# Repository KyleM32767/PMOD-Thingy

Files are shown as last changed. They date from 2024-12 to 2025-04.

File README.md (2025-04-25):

# PMOD-Thingy

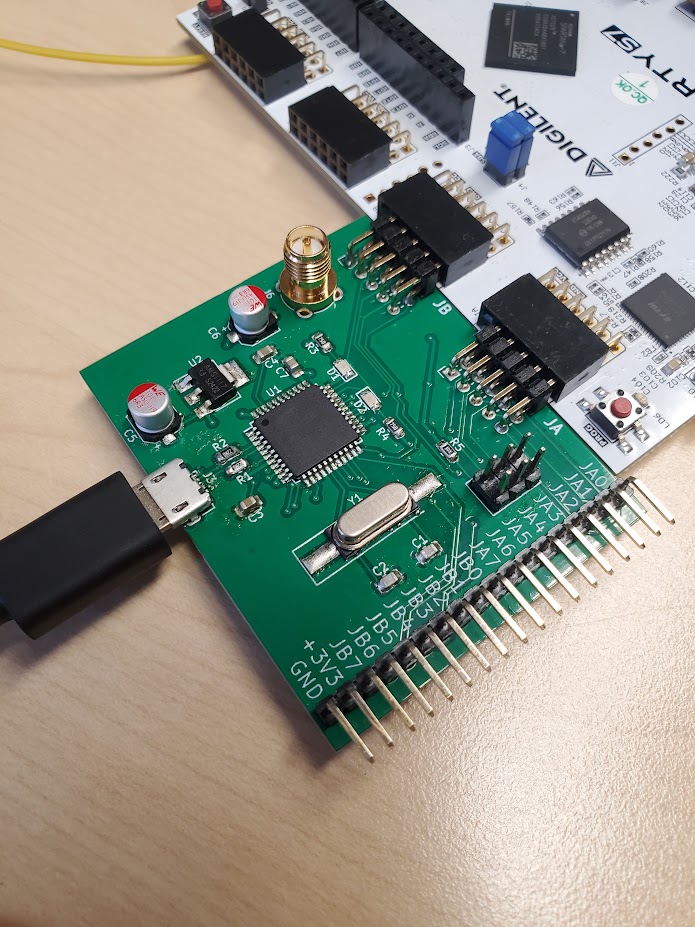
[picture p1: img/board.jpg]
PMOD thingy plugged into Arty S7


PMOD Thingy is, essentially, an Arduino Leonardo modified and repackaged to interface with basically any Digilent FPGA board via the PMOD headers. I designed it to streamline hardware security experiments done by myself and my colleagues at WPI Vernam Lab, where we'd use a 3.3V Arduino board to interface with an FPGA through the PMOD headers.

**Note: this is a custom board with a different pinout and clock frequency from a typical Arduino, so you must follow the setup procedure before use!**

## Pinouts

```
                  (top edge of board)
_______________________________________________________
-----------------------         -----------------------
| GND JB3 JB2 JB1 JB0 |         | GND JA3 JA2 JA1 JA0 |
| GND JB7 JB6 JB5 JB4 |         | GND JA7 JA6 JA5 JA4 |
-----------------------         -----------------------
```

| PMOD header | Digital I/O pin | Atmega32U4 pin |
|:---|:---|:---|
| JA0 | 0 | PB0 |
| JA1 | 1 / SPI SCK | PB1 |
| JA2 | 2 / SPI MOSI | PB2 |
| JA3 | 3 / SPI MISO | PB3 |
| JA4 | 4 | PB4 |
| JA5 | 5 | PB5 |
| JA6 | 6 | PB6 |
| JA7 | 7 | PB7 |
| JB0 | 8 / I2C SCL | PD0 |
| JB1 | 9 / I2C SDA | PD1 |
| JB2 | 10 / UART RX | PD2 |
| JB3 | 11 / UART TX | PD3 |
| JB4 | 12 | PD4 |
| JB5 | 13 | PD5 |
| JB6 | 14 | PD6 |
| JB7 | 15 | PD7 |

Although you can use the digital I/O numbers, there are macros for the PMOD headers, so you don't have to keep track of which header connects to which pin.

```cpp
// output 0 on JA6
pinMode(JA6, OUTPUT);
digitalWrite(JA6, LOW);

// input on JB2
pinMode(JB2, INPUT);
if (digitalRead(JB2) == HIGH)
	Serial.println("1 on JB2");
else
	Serial.println("0 on JB2");
```

Each PMOD header is also connected to a single port on the Atmega32U4, which means you can also read and write them bytewise using the data direction and port registers if that is more your speed. There are the macros `DDR_JA`/`DDR_JB` (data direction), `PIN_JA`/`PIN_JB` (input), and `PORT_JA`/`PORT_JB` (output) for that purpose. For more information, refer to [section 10.4 of the ATmega32U4 datasheet](https://ww1.microchip.com/downloads/en/devicedoc/atmel-7766-8-bit-avr-atmega16u4-32u4_datasheet.pdf#page=84). This makes reading and writing multiple bits much, much faster. The code snippet below is functionally identical to the one above...

```cpp
// output 0 on JA6
DDR_JA |= (1<<6);
PORT_JA &= ~(1<<6);

// read input on JB2
DDR_JB %= ~(1<<2);
if (PIN_JB & (1<<2))
	Serial.println("1 on JB2");
```

## Burning the bootloader

You can burn the bootloader to the PMOD thingy as you would any other Arduino board through the Arduino IDE. I prefer to do this with [another Arduino running ArduinoISP](https://docs.arduino.cc/built-in-examples/arduino-isp/ArduinoISP/) personally. It doesn't actually matter if you use a 3.3V or a 5V board, so long as you do not connect the PMOD Thingy to any other power source (i.e. USB) while using it. Just remember the capacitor between reset and ground!

**PLEASE NOTE: I MADE A MISTAKE!** If you have one of the original v1 boards I made, I mixed up the SPI pins, so a few of the ICSP pins (SCK, MOSI, MISO) are wrong, though VCC, GND, and RESET are correct. I corrected the labels for the SPI pins on the schematic in this repository and this readme, but not on the layout and gerber files, so if you make one of these yourself you will have this issue as well. In order to burn the bootloader from an Arduino Uno as ISP, you need to make the following connections...

| Pin | Arduino Uno as ISP | PMOD Thingy V1 |
|:---|:---|:---|
| MOSI  | D11 / ICSP-4 | JA2 |
| MISO  | D12 / ICSP-1 | JA3 |
| SCK | D13 / ICSP-3 | JA1 |
| reset | D10 | ICSP-5 |

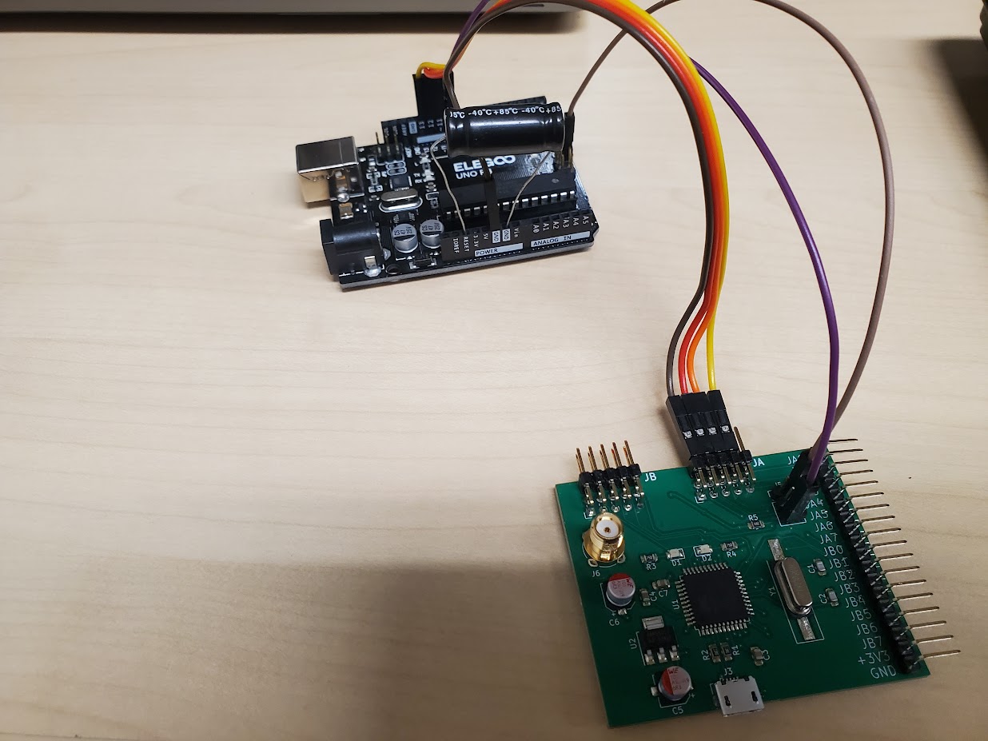
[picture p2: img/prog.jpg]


The PMOD Thingy runs the same bootloader as the Sparkfun Pro Micro 3.3V / 8MHz, though you can use the bootloader for any Atmega32u4-based Arduino with an 8MHz clock (as opposed to the 16MHz clock most boards run), if any other such boards exist at all. As such, you will need to [install the pro micro board to the Arduino IDE](https://learn.sparkfun.com/tutorials/pro-micro--fio-v3-hookup-guide#windows_boardaddon). Once that is installed, set up and connect your ArduinoISP, select "SparkFun Pro Micro" under *Tools>Board*, select "ATmega32U4 (3.3V, 8MHz)" under *Tools>Processor*, then click *Tools>Burn Bootloader*.

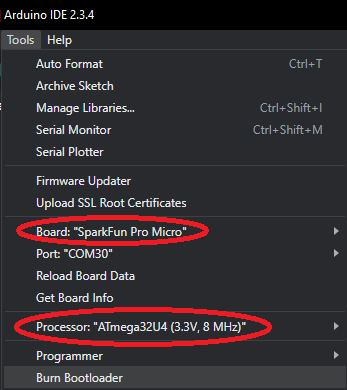
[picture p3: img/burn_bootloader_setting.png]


## Adding board to Arduino IDE

While you techincally *can* program the PMOD Thingy as a Sparkfun Pro Micro, it has an entirely different pinout from any standard Arduino. As such it needs its own special board definition. Use the following steps to add it...

1. **Open the Arduino AVR platform folder.** The exact location depends on your OS...
	* Windows
		- Arduino IDE 1.x - `C:\Program Files (x86)\Arduino\hardware\arduino\avr`
		- Arduino IDE 2.x - `C:\Users\{username}\AppData\Local\Arduino15\packages\arduino\hardware\avr\1.8.6`
	* macOS - `/Users/{username}/Library/Arduino15/packages/arduino/hardware/avr/1.8.6`
	* Linux - `/home/{username}/.arduino15/packages/arduino/hardware/avr/1.8.6`

2. **Modify `boards.txt`.** Paste the contents of `arduino_ide_config/boards_addon.txt` to the bottom of `boards.txt`

3. **Add a `pins_arduino.h` variant called 'pmodthingy.'** In the `variants` folder, create a folder called `pmodthingy` and paste `arduino_ide_config/pins_arduino.h`

4. **Restart Arduino IDE.** Once that is done, you should see "PMOD Thingy" as an option under *Tools>Board>Arduino AVR Boards*

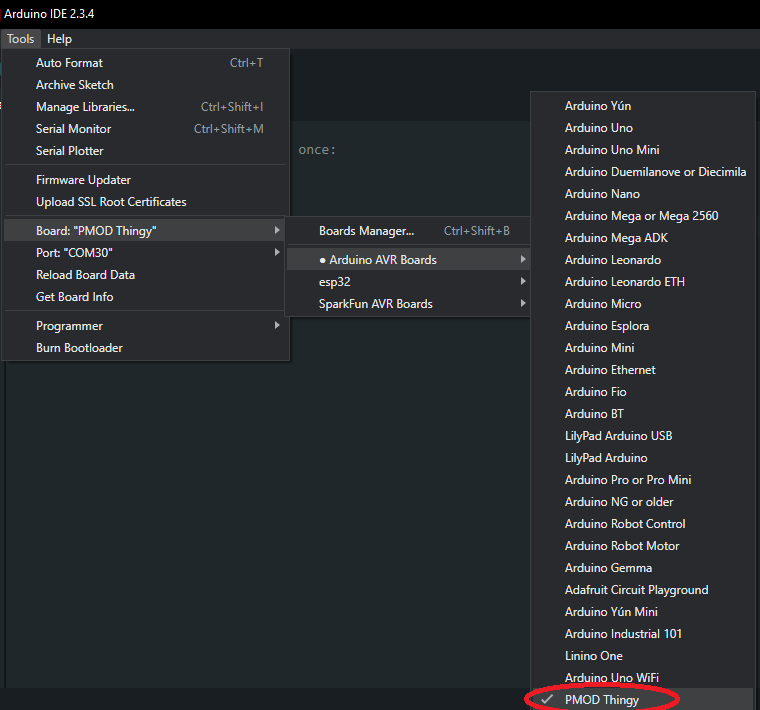
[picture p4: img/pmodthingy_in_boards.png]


## A few notes about Serial...

Since the PMOD Thingy has native USB you cannot use the serial port until it is actually open. In practice, this means you must put `while (!Serial) {}` or something after you initialize the serial interface and before you do anything with it. For more info, read the [official Arduino documentation](https://www.arduino.cc/reference/cs/language/functions/communication/serial/ifserial/)

**`SerialEvent()` does not work on Atmega32u4 based boards, such as the PMOD thingy.** However, completely undocumented is the ability to use it anyways with `SerialEventRun()`...

```cpp
// add this to your sketch make serialEvent() work
void SerialEventRun() {
	if (Serial.available())
		SerialEvent();
}
```

[People say using `serialEvent()` is the "wrong" thing to do](https://forum.arduino.cc/t/serialevent-with-the-esplora-leo-micro/173720), but it's what I've always done because I didn't know better at the time, and it works fine for what I usually do.

## "y no analog?"

The PMOD headers on FPGA boards, at least the ones I've used, are digital. Some boards have a PMOD header for XADC, but I've never used them and in fact have no idea how they work (as of writing this). As such, I've completely removed anything to do with analog inputs, though some of the pins are capable of analog and in fact are used as analog I/O on the Leonardo and Pro Micro.

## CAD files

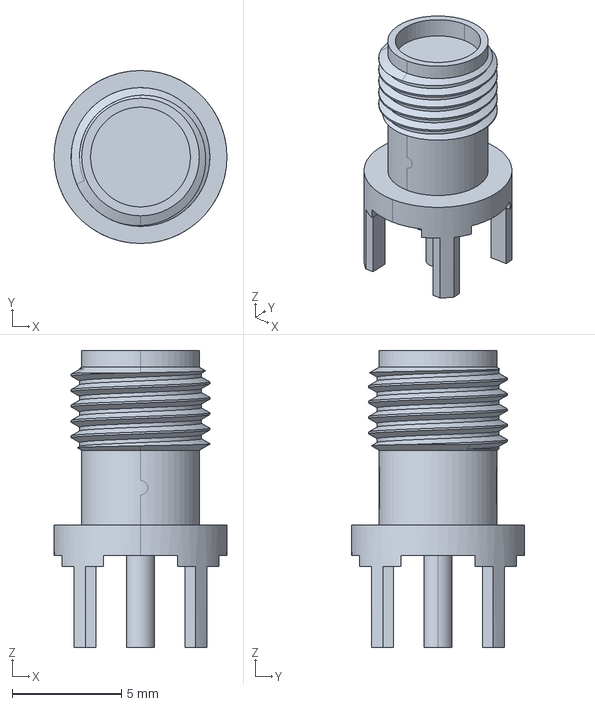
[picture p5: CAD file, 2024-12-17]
CONSMA001_C_G/CONSMA001-C-G.step
7.92 x 7.92 x 13.6 mm

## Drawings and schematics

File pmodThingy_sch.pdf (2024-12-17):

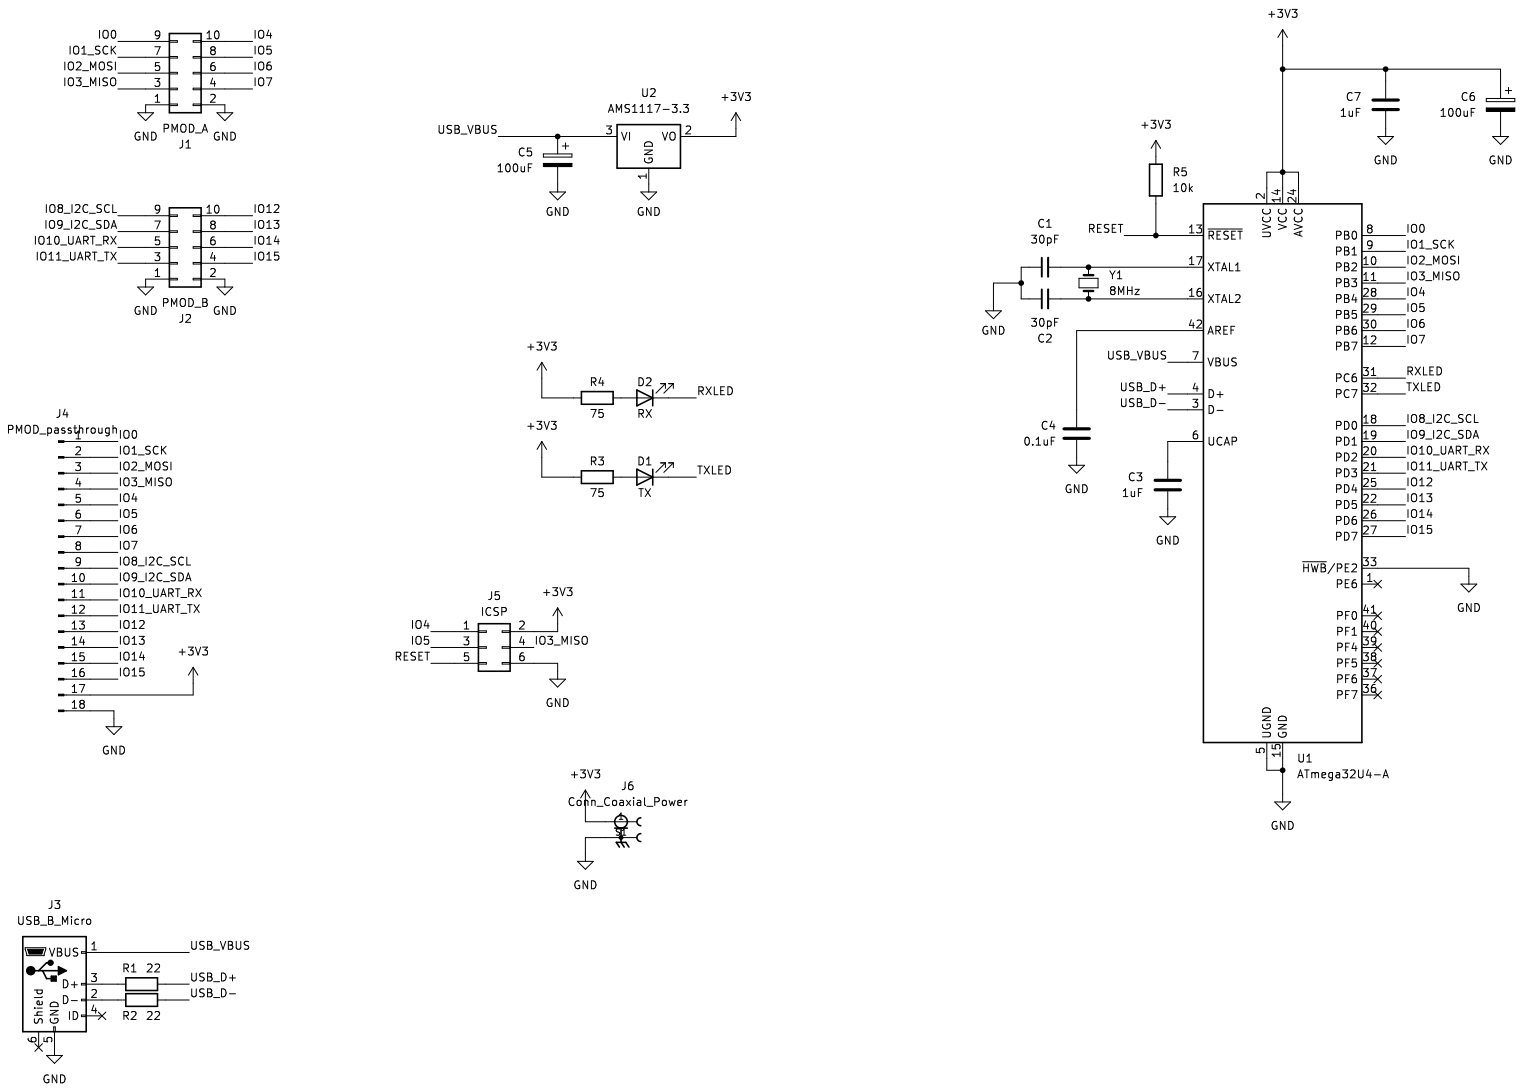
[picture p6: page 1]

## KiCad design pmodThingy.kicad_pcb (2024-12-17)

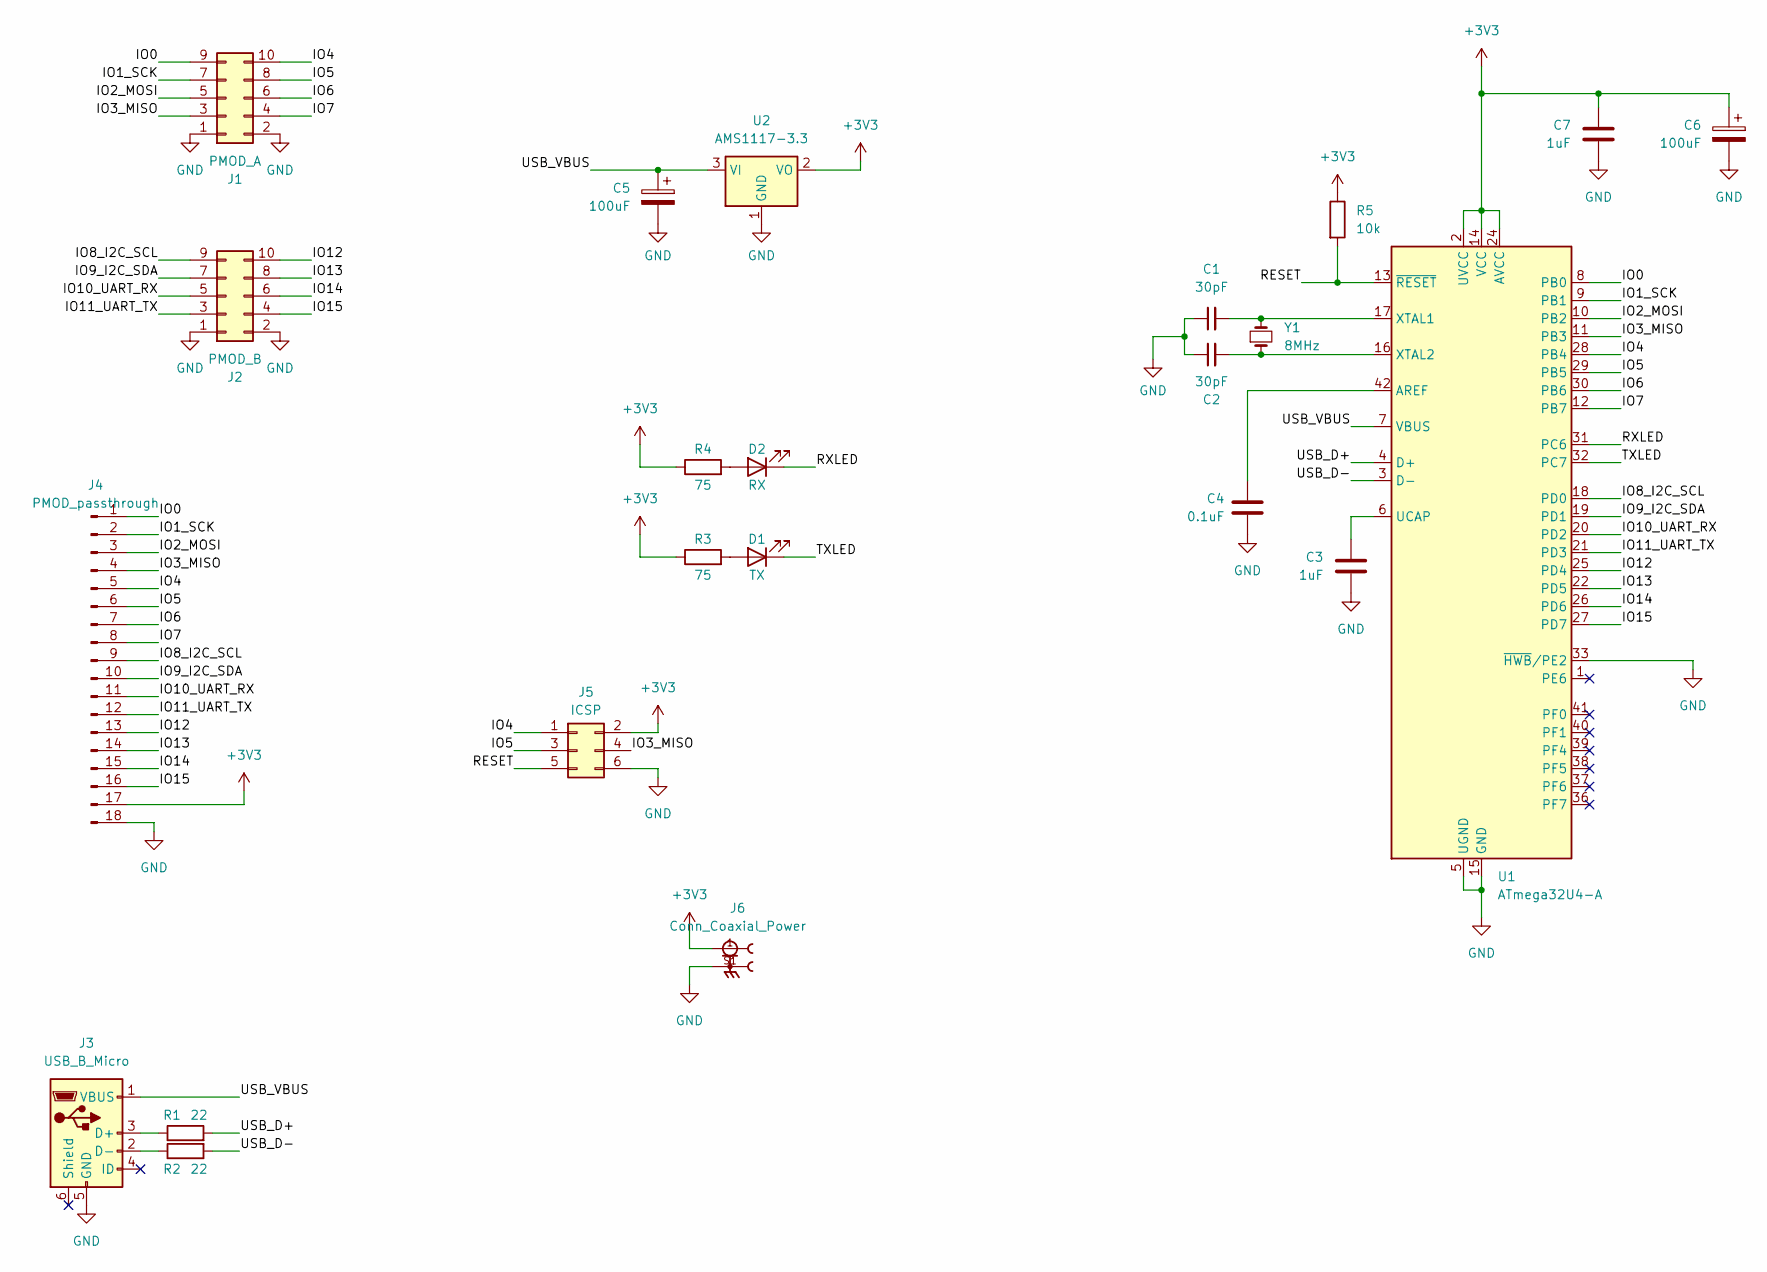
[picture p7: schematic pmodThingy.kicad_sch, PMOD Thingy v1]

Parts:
C1, C2: 30pF; C_0805_2012Metric_Pad1.18x1.45mm_HandSolder
C3, C7: 1uF; C_0805_2012Metric_Pad1.18x1.45mm_HandSolder
C4: 0.1uF; C_0805_2012Metric_Pad1.18x1.45mm_HandSolder
C5, C6: 100uF; CP_Elec_5x5.3
D1: TX; LED_0805_2012Metric_Pad1.15x1.40mm_HandSolder
D2: RX; LED_0805_2012Metric_Pad1.15x1.40mm_HandSolder
J1: PMOD_A; PinHeader_2x05_P2.54mm_Horizontal
J2: PMOD_B; PinHeader_2x05_P2.54mm_Horizontal
J3: USB_B_Micro; USB_Micro-B_GCT_USB3076-30-A
J4: PMOD_passthrough; PinHeader_1x18_P2.54mm_Horizontal
J5: ICSP; PinHeader_2x03_P2.54mm_Vertical
J6: Conn_Coaxial_Power; LINX_CONSMA001-C-G
R1, R2: 22; R_0805_2012Metric_Pad1.20x1.40mm_HandSolder
R3, R4: 75; R_0805_2012Metric_Pad1.20x1.40mm_HandSolder
R5: 10k; R_0805_2012Metric_Pad1.20x1.40mm_HandSolder
U1: ATmega32U4-A; TQFP-44_10x10mm_P0.8mm
U2: AMS1117-3.3; SOT-223-3_TabPin2
Y1: 8MHz; Crystal_SMD_HC49-SD_HandSoldering

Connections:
+3V3: C6.1, C7.1, J4.17, J5.2, J6.1, R3.1, R4.1, R5.1, U1.2 (UVCC), U1.14 (VCC), U1.24 (AVCC), U1.34 (VCC), U1.44 (AVCC), U2.2 (VO)
/IO0: J1.9, J4.1, U1.8 (PB0)
/IO1_SCK: J1.7, J4.2, U1.9 (PB1)
/IO2_MOSI: J1.5, J4.3, U1.10 (PB2)
/IO3_MISO: J1.3, J4.4, J5.4, U1.11 (PB3)
/IO4: J1.10, J4.5, J5.1, U1.28 (PB4)
/IO5: J1.8, J4.6, J5.3, U1.29 (PB5)
/IO6: J1.6, J4.7, U1.30 (PB6)
/IO7: J1.4, J4.8, U1.12 (PB7)
/IO8_I2C_SCL: J2.9, J4.9, U1.18 (PD0)
/IO9_I2C_SDA: J2.7, J4.10, U1.19 (PD1)
/IO10_UART_RX: J2.5, J4.11, U1.20 (PD2)
/IO11_UART_TX: J2.3, J4.12, U1.21 (PD3)
/IO12: J2.10, J4.13, U1.25 (PD4)
/IO13: J2.8, J4.14, U1.22 (PD5)
/IO14: J2.6, J4.15, U1.26 (PD6)
/IO15: J2.4, J4.16, U1.27 (PD7)
/RESET: J5.5, R5.2, U1.13 (~RESET)
/RXLED: D2.1 (K), U1.31 (PC6)
/TXLED: D1.1 (K), U1.32 (PC7)
/USB_D+: R1.2, U1.4 (D+)
/USB_D-: R2.2, U1.3 (D-)
/USB_VBUS: C5.1, J3.1 (VBUS), U1.7 (VBUS), U2.3 (VI)
GND: C1.1, C2.1, C3.2, C4.2, C5.2, C6.2, C7.2, J1.1, J1.2, J2.1, J2.2, J3.5 (GND), J4.18, J5.6, J6.S1, U1.5 (UGND), U1.15 (GND), U1.23 (GND), U1.33 (~HWB/PE2), U1.35 (GND), U1.43 (GND), U2.1 (GND)
unnamed: D1.2 (A), R3.2
unnamed: D2.2 (A), R4.2
unnamed: J3.3 (D+), R1.1
unnamed: J3.2 (D-), R2.1
unnamed: C4.1, U1.42 (AREF)
unnamed: C3.1, U1.6 (UCAP)
unnamed: C1.2, U1.17 (XTAL1), Y1.2
unnamed: C2.2, U1.16 (XTAL2), Y1.1

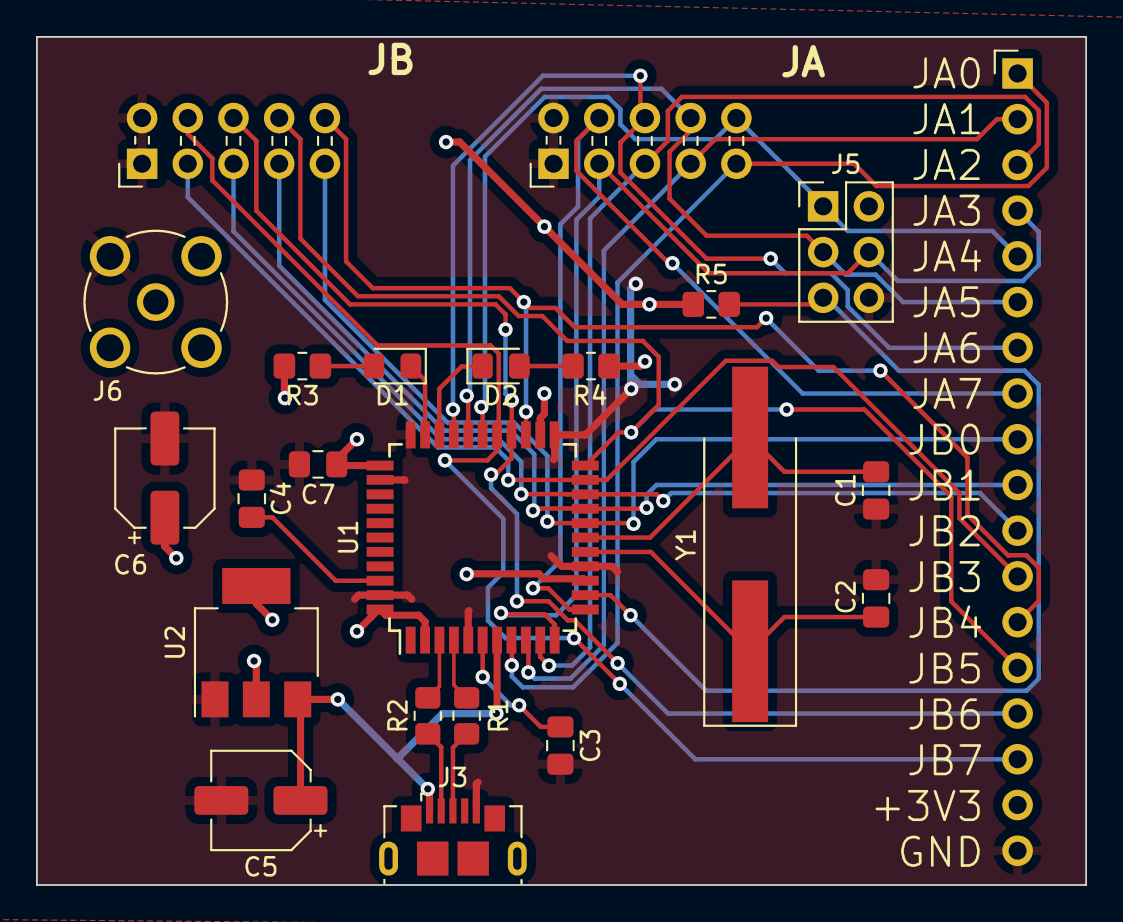
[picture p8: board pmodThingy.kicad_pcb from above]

Board: 2 copper layers, 58.3 x 47.1 mm, 23 parts (0 on the bottom side), 32 nets.

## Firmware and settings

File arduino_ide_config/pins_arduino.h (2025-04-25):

/*
  pins_arduino.h - Pin definition functions for Arduino
  Part of Arduino - http://www.arduino.cc/

  Copyright (c) 2007 David A. Mellis

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
  You should have received a copy of the GNU Lesser General
  Public License along with this library; if not, write to the
  Free Software Foundation, Inc., 59 Temple Place, Suite 330,
  Boston, MA  02111-1307  USA
*/

#ifndef Pins_Arduino_h
#define Pins_Arduino_h

#include <avr/pgmspace.h>

// Workaround for wrong definitions in "iom32u4.h".
// This should be fixed in the AVR toolchain.
#undef UHCON
#undef UHINT
#undef UHIEN
#undef UHADDR
#undef UHFNUM
#undef UHFNUML
#undef UHFNUMH
#undef UHFLEN
#undef UPINRQX
#undef UPINTX
#undef UPNUM
#undef UPRST
#undef UPCONX
#undef UPCFG0X
#undef UPCFG1X
#undef UPSTAX
#undef UPCFG2X
#undef UPIENX
#undef UPDATX
#undef TCCR2A
#undef WGM20
#undef WGM21
#undef COM2B0
#undef COM2B1
#undef COM2A0
#undef COM2A1
#undef TCCR2B
#undef CS20
#undef CS21
#undef CS22
#undef WGM22
#undef FOC2B
#undef FOC2A
#undef TCNT2
#undef TCNT2_0
#undef TCNT2_1
#undef TCNT2_2
#undef TCNT2_3
#undef TCNT2_4
#undef TCNT2_5
#undef TCNT2_6
#undef TCNT2_7
#undef OCR2A
#undef OCR2_0
#undef OCR2_1
#undef OCR2_2
#undef OCR2_3
#undef OCR2_4
#undef OCR2_5
#undef OCR2_6
#undef OCR2_7
#undef OCR2B
#undef OCR2_0
#undef OCR2_1
#undef OCR2_2
#undef OCR2_3
#undef OCR2_4
#undef OCR2_5
#undef OCR2_6
#undef OCR2_7

#define NUM_DIGITAL_PINS  18
#define NUM_ANALOG_INPUTS 0

#define TX_RX_LED_INIT	DDRC |= (1<<6), DDRC |= (1<<7)
#define TXLED0			PORTC |= (1<<7)
#define TXLED1			PORTC &= ~(1<<7)
#define RXLED0			PORTC |= (1<<6)
#define RXLED1			PORTC &= ~(1<<6)

#define PIN_WIRE_SDA         (8)
#define PIN_WIRE_SCL         (9)

// port and data direction registers for byte-wise writing PMOD headers
#define DDR_JA  DDRB
#define PORT_JA PORTB
#define PIN_JA  PINB
#define DDR_JB  DDRD
#define PORT_JB PORTD
#define PIN_JB  PIND

// macros for each pin
#define JA0 0
#define JA1 1
#define JA2 2
#define JA3 3
#define JA4 4
#define JA5 5
#define JA6 6
#define JA7 7
#define JB0 8
#define JB1 9
#define JB2 10
#define JB3 11
#define JB4 12
#define JB5 13
#define JB6 14
#define JB7 15


static const uint8_t SDA = PIN_WIRE_SDA;
static const uint8_t SCL = PIN_WIRE_SCL;

// #define LED_BUILTIN 12
#define LED_BUILTIN_RX 16
#define LED_BUILTIN_TX 17

// Map SPI port to 'new' pins D14..D17
#define PIN_SPI_SS    (0)
#define PIN_SPI_MOSI  (2)
#define PIN_SPI_MISO  (3)
#define PIN_SPI_SCK   (1)

static const uint8_t SS   = PIN_SPI_SS;
static const uint8_t MOSI = PIN_SPI_MOSI;
static const uint8_t MISO = PIN_SPI_MISO;
static const uint8_t SCK  = PIN_SPI_SCK;

#define digitalPinToPCICR(p)    ( ((p) >= 0 && (p) <= 7) ? (&PCICR) : ((uint8_t *)0))
#define digitalPinToPCICRbit(p) 0
#define digitalPinToPCMSK(p)    (((p) >= 0 && (p) <= 7) ? (&PCMSK0) : ((uint8_t *)0))
#define digitalPinToPCMSKbit(p) (p)

//	__AVR_ATmega32U4__ has an unusual mapping of pins to channels
extern const uint8_t PROGMEM analog_pin_to_channel_PGM[];
#define analogPinToChannel(P)  ( pgm_read_byte( analog_pin_to_channel_PGM + (P) ) )

#define digitalPinHasPWM(p)         ((p) == 8 || (p) == 15 || (p) == 5 || (p) == 6 || (p) == 7)

#define digitalPinToInterrupt(p) ((p) == 10 ? 2 : ((p) == 11 ? 3 : ((p) == 9 ? 1 : ((p) == 8 ? 0 : NOT_AN_INTERRUPT))))

#ifdef ARDUINO_MAIN

// On the Arduino board, digital pins are also used
// for the analog output (software PWM).  Analog input
// pins are a separate set.

// ATMEL ATMEGA32U4 / ARDUINO LEONARDO
//
// D0				PD2					RXD1/INT2
// D1				PD3					TXD1/INT3
// D2				PD1		SDA			SDA/INT1
// D3#				PD0		PWM8/SCL	OC0B/SCL/INT0
// D4		A6		PD4					ADC8
// D5#				PC6		???			OC3A/#OC4A
// D6#		A7		PD7		FastPWM		#OC4D/ADC10
// D7				PE6					INT6/AIN0
//
// D8		A8		PB4					ADC11/PCINT4
// D9#		A9		PB5		PWM16		OC1A/#OC4B/ADC12/PCINT5
// D10#		A10		PB6		PWM16		OC1B/0c4B/ADC13/PCINT6
// D11#				PB7		PWM8/16		0C0A/OC1C/#RTS/PCINT7
// D12		A11		PD6					T1/#OC4D/ADC9
// D13#				PC7		PWM10		CLK0/OC4A
//
// A0		D18		PF7					ADC7
// A1		D19		PF6					ADC6
// A2		D20 	PF5					ADC5
// A3		D21 	PF4					ADC4
// A4		D22		PF1					ADC1
// A5		D23 	PF0					ADC0
//
// New pins D14..D17 to map SPI port to digital pins
//
// MISO		D14		PB3					MISO,PCINT3
// SCK		D15		PB1					SCK,PCINT1
// MOSI		D16		PB2					MOSI,PCINT2
// SS		D17		PB0					RXLED,SS/PCINT0
//
// TXLED	D30		PD5					XCK1
// RXLED	D17	    PB0
// HWB				PE2					HWB

// these arrays map port names (e.g. port B) to the
// appropriate addresses for various functions (e.g. reading
// and writing)
const uint16_t PROGMEM port_to_mode_PGM[] = {
	NOT_A_PORT,
	NOT_A_PORT,
	(uint16_t) &DDRB,
	(uint16_t) &DDRC,
	(uint16_t) &DDRD,
	(uint16_t) &DDRE,
	(uint16_t) &DDRF,
};

const uint16_t PROGMEM port_to_output_PGM[] = {
	NOT_A_PORT,
	NOT_A_PORT,
	(uint16_t) &PORTB,
	(uint16_t) &PORTC,
	(uint16_t) &PORTD,
	(uint16_t) &PORTE,
	(uint16_t) &PORTF,
};
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

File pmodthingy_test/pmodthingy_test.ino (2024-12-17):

void serialEventRun() {
	if (Serial.available())
		serialEvent();
}


// keys to press to flip JA bits
const char KEYS_JA[9] = "qwertyui";

// keys to press to flip JB bits
const char KEYS_JB[9] = "asdfghjk";

// bitfield with status of JA bits
uint8_t out_ja = 0b00000000;

// bitfield with status of JB bits
uint8_t out_jb = 0b00000000;

// PMOD JA pin numbers
const int PINS_JA[8] = {0,  1,  2,  3,  4,  5,  6,  7 };

// PMOD JB pin numbers
const int PINS_JB[8] = {8,  9,  10, 11, 12, 13, 14, 15};

void serialEvent() {
	char rx = Serial.read();

	
	// set relevant bit
	for (int i=0; i<8; i++) {

		// check for JA toggle key
		if (rx == KEYS_JA[i]) {

			// toggle relevant bitfield bit
			out_ja ^= (1<<i); // toggle relevant bitfield bit
			
			// update relevant bit
			if (out_ja & (1<<i))
				digitalWrite(PINS_JA[i], HIGH);
			else
				digitalWrite(PINS_JA[i], LOW);
		}

	
		// check for JB toggle key
		if (rx == KEYS_JB[i]) {

			// toggle relevant bitfield bit
			out_jb ^= (1<<i); // toggle relevant bitfield bit
			
			// update relevant bit
			if (out_jb & (1<<i))
				digitalWrite(PINS_JB[i], HIGH);
			else
				digitalWrite(PINS_JB[i], LOW);
		}
	}


	// print status
	for (int i=7; i>=0; i--) {
		Serial.print((out_ja >> i) & 0b00000001);
	}
	Serial.print('\t');
	for (int i=7; i>=0; i--) {
		Serial.print((out_jb >> i) & 0b00000001);
	}

	Serial.print('\n');

}

void setup() {
	Serial.begin(9600);

	for (int i=0; i<8; i++) {
		pinMode(PINS_JA[i], OUTPUT);
		pinMode(PINS_JB[i], OUTPUT);
	}
}

void loop() {
	// put your main code here, to run repeatedly:

}

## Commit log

2024-12-17 add v1 KiCad files
    [CONSMA001-C-G.step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]
2024-12-17 add arduino IDE config files
2024-12-17 relabel some pins on schematic
    [pmodThingy.kicad_pcb, pmodThingy.kicad_sch]
2025-04-25 added missing macro for JA and JB inputs
    [pins_arduino.h]
